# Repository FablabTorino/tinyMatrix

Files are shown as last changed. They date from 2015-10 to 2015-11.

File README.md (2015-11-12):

# TinyMatrix
A Tiny Matrix, also called e-jewel, is a little electronic Jewel that changes animations every time you press the button.

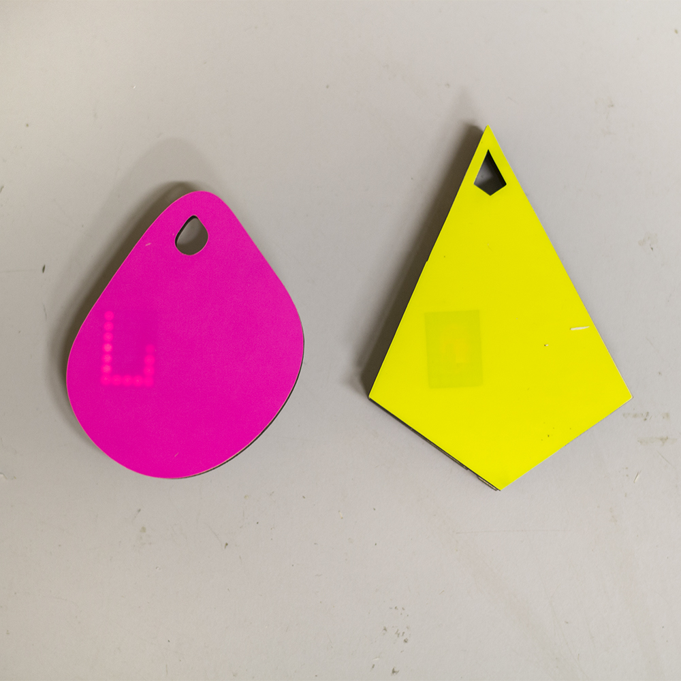
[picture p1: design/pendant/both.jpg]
 

# Programming the ATTINY4313

In order to program the AT TINY 4313 you first need to install the ATTiny core in Arduino 1.6.4.

You can do that by following [this tutorial] (https://github.com/SpenceKonde/ATTinyCore)

To connect the ATTINY to the Arduino board perhaps you can build [your own shield] (http://www.instructables.com/id/Arduino-ATtiny2313-Programming-Shield/step2/Prototype-and-Pinout/).

Now you can load Arduino's sketches. 

# Loading sketches

In this repository you will find an Arduino sketch to load some animation ([Arduino code](https://github.com/FablabTorino/tinyMatrix/tree/master/code/arduino%20programming/LedMatrix_ATtiny%20))

and a Processing sketch to create new ones ([Processing code](https://github.com/FablabTorino/tinyMatrix/tree/master/code/Processing%20sketch)). 

This last sketch will print on the console the code that you can copy and paste in Arduino.

To create new animations you have to play the processing program.

A window like this will open 

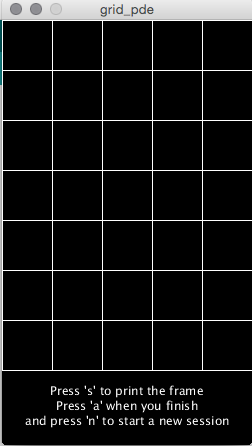
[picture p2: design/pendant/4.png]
  

Then you just draw your animation frame by frame. 

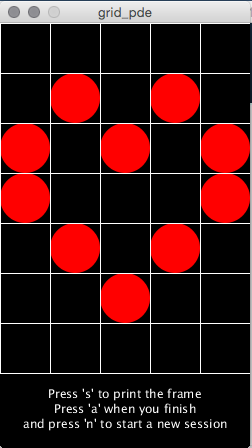
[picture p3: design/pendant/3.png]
 




To save a new frame press 's', and when you are done press 'a' so you get the number of frames and the complete code.

Now copy what Processing printed to the console

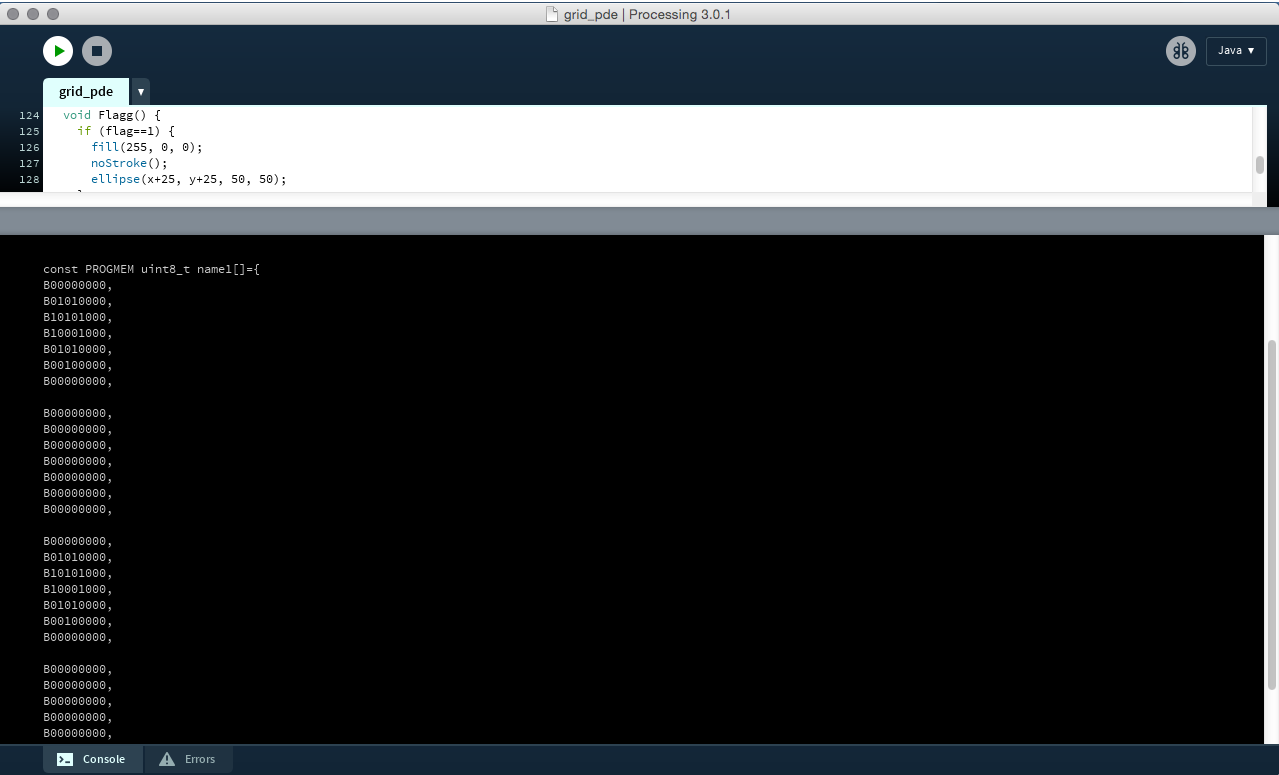
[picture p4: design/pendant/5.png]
 

and paste it in the Arduino sketch in the images.h file

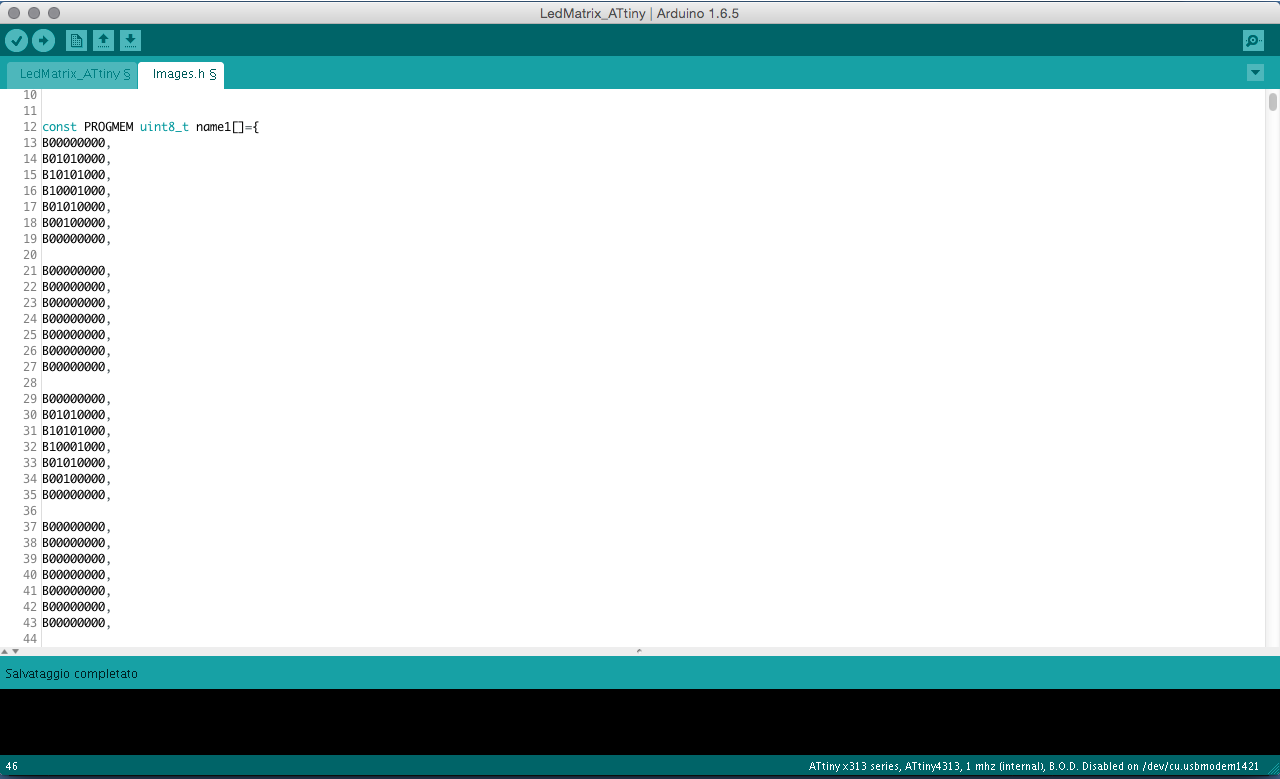
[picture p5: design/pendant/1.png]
 

now in the void loop section of the Arduino sketch create a new 'case' in the switch function

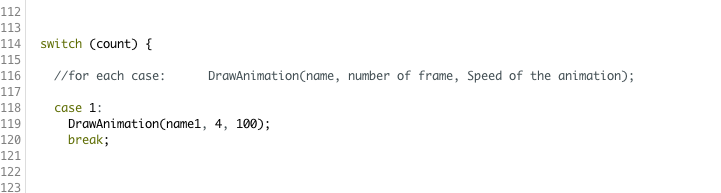
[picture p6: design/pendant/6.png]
 

now you can upload the code to the ATTINY

and you are done!

# Creating the jewel

You can download the .dxf files from [here] (https://github.com/FablabTorino/tinyMatrix/tree/master/design/DXF) or you

can draw your own, just remember to use a 6mm poplar plywood.

First thing to do is to build the structure following this instructions:
</br>
</br>
</br>
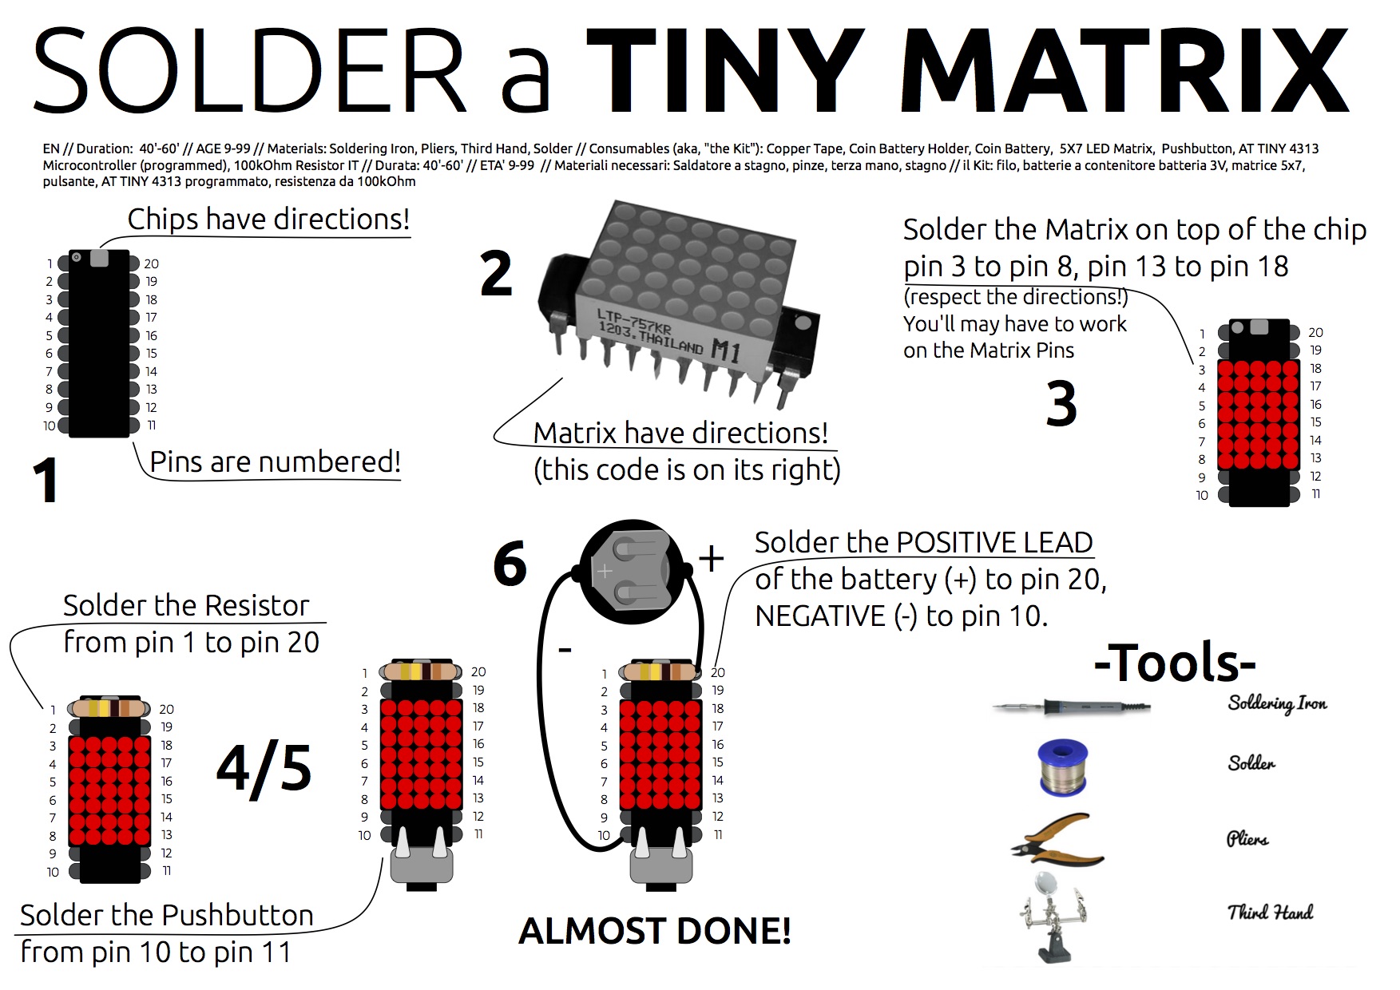
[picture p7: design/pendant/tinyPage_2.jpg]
 
</br>
</br>
</br>
The whole process should look like this:
</br>
</br>
</br>
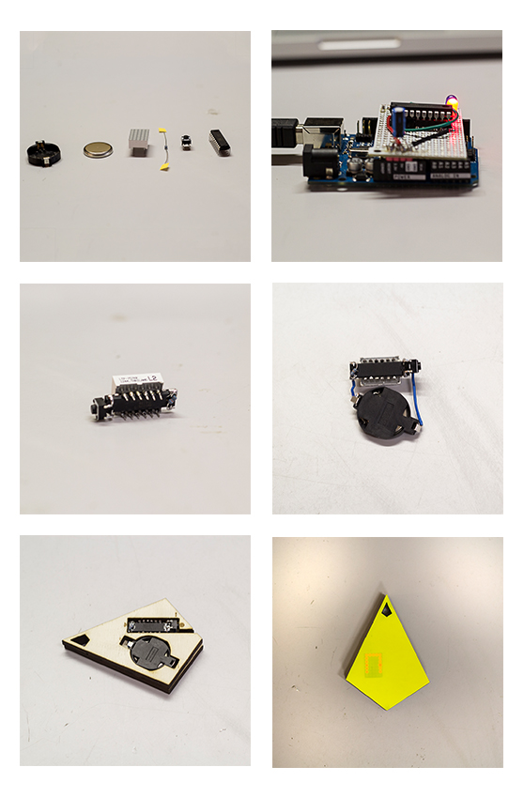
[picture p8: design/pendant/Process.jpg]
 
</br>
</br>
</br>

## Notes about the wiring
To manipulate pins and leds take a look at this scheme:
</br>
</br>
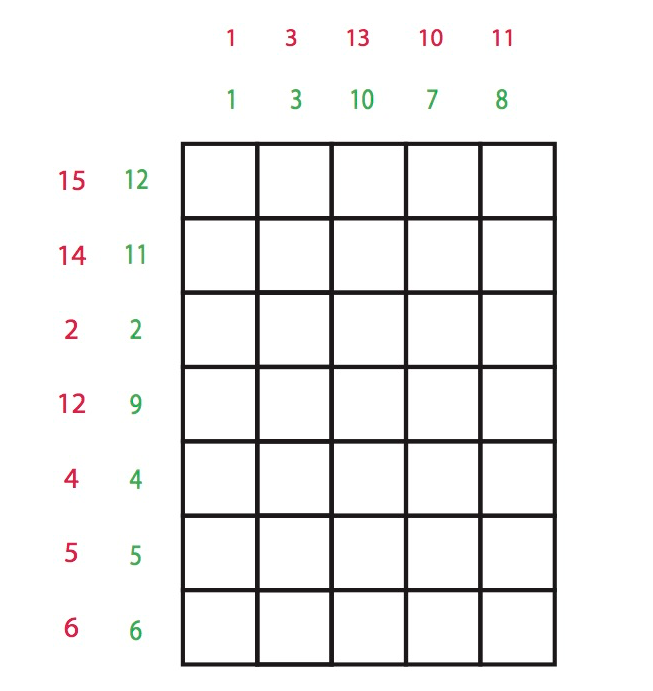
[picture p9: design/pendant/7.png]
 
</br>
</br>
Green numbers rapresent the led-matrix's pin and red numbers are the ATTINY's ones.

So, for example, if you want to turn the first led on (Up-Left) you have to set:

pin15=HIGH;
</br>
pin1=LOW;

# BOM

| part		 | Quantity | Part number | Distributor Part Number |  LINK|
| --- |:---:| :---:| :---:| :---:|
| pushbutton | 1 | 450-1650-ND | FSM4JH | 
| coin battery | 1 | P189-ND | CR2032 |
| battery  holder | 1 | BC2032-F1-ND	| BC2032-F1 |
| 100K resistors | 1 | CF18JT100KCT-ND | CF18JT100K |
| AT TINY 4313 | 1 | ATTINY4313-PU-ND | ATTINY4313-PU |
| 5X7 red matrix | 1 | 160-1555-5-ND	| LTP-757KR |

#Credits

The project was inspired By [TigerUp] (https://sites.google.com/site/tinymatrix/) and customized by Franco Magni and Federico Vanzati in 2012, at Fablab Torino, further developed by Stefano Paradiso, Tommaso Laterza and Lorenzo romagnoli in 2015.

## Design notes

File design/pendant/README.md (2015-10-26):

# Assembly instructions

you don't need any external material, casing or circuit board to assembly your pendant.
Just follow this simple guidelines.

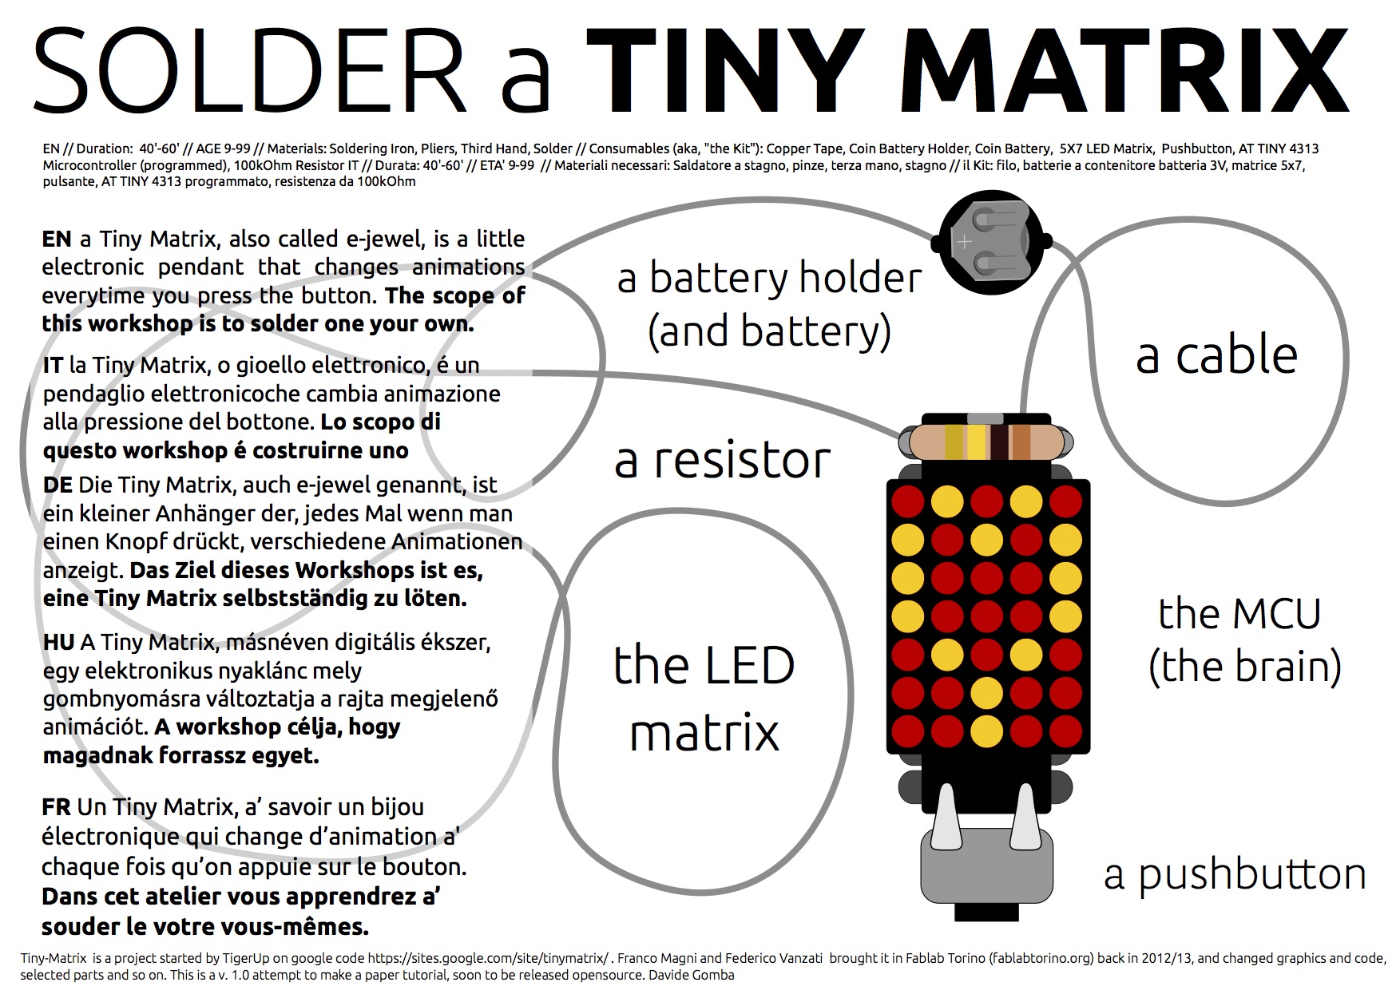
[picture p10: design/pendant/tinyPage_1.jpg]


Logo Title Text 1

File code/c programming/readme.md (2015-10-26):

##Instructions

this folder contains two version of the firmware:

**TinyMatrix**: the original project  
**TinyMatrixCountdown**: contains also a countdown (from 9 to 0) animation.

This is not an Arduino like program but there is a make file to compile it. Make sure you have the AVR-GCC toolchain installed.
To compile the program:
1. open a command shell and move to the Tiny Matrix directory
2. edit the Makefile `PROGRAMMER` field with the AVR programmer name you have
3. run the command "make all" and the HEX file to load on the ATtiny will be generated
4. run make fuse and the fuses for the Attiny4313 will be burned
5. run make program to flash the firmware on the Attiny4313

##Functioning 
TODO: description of the logic

##Credits
The origial projects was created by TigerUp (https://sites.google.com/site/tinymatrix/)

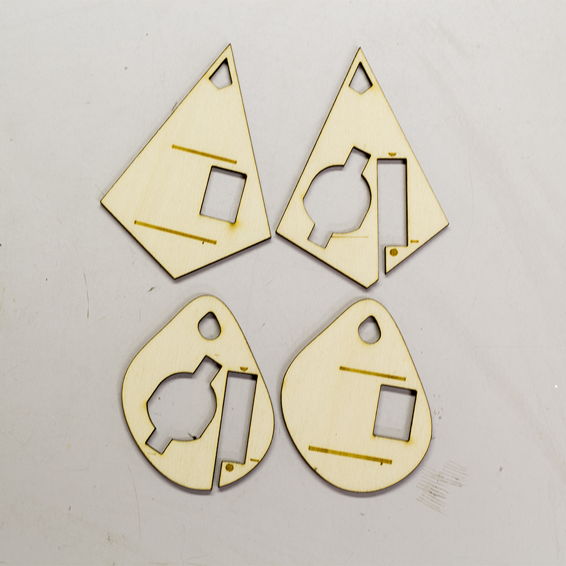
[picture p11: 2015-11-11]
design/pendant/wood.jpg

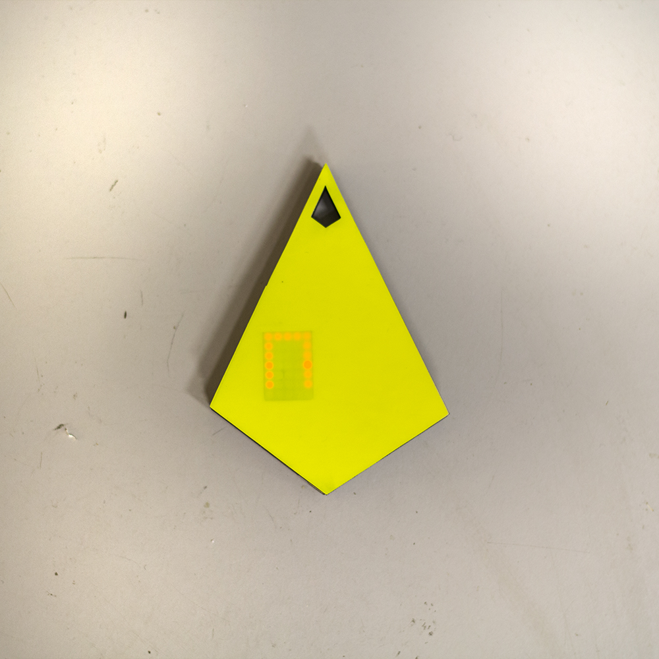
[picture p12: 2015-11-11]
design/pendant/FrontVynil.jpg

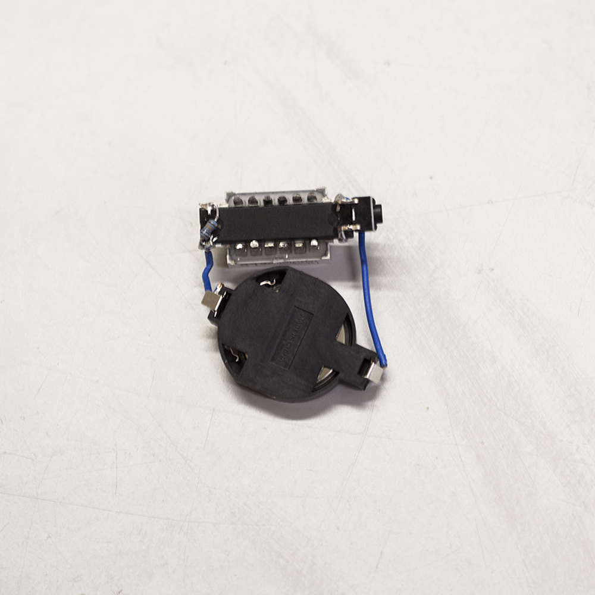
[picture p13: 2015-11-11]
design/pendant/battery.jpg

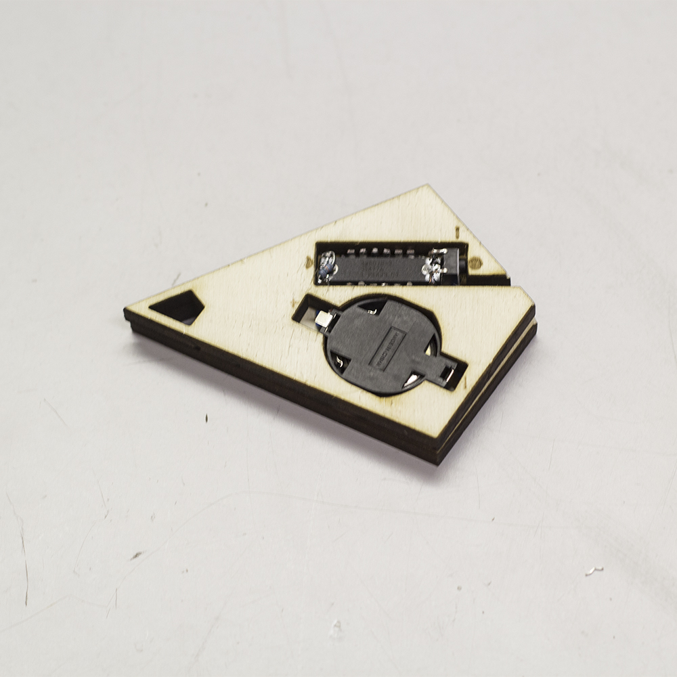
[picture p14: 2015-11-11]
design/pendant/Pendente.jpg

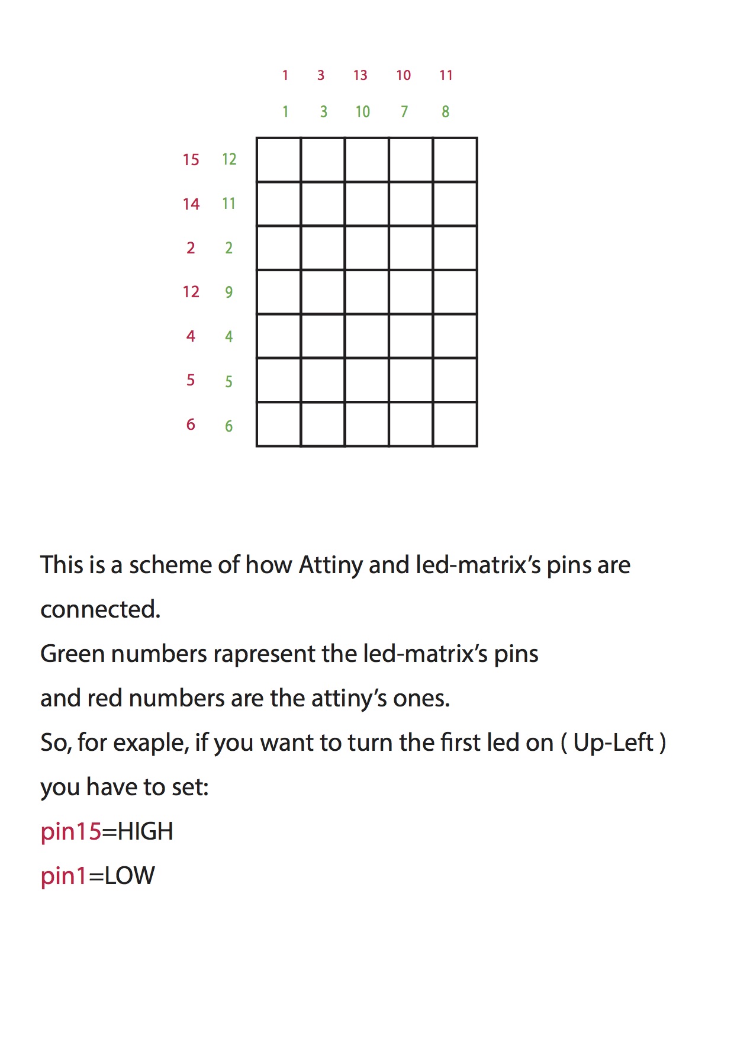
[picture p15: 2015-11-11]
design/pendant/PinsGrid.jpg

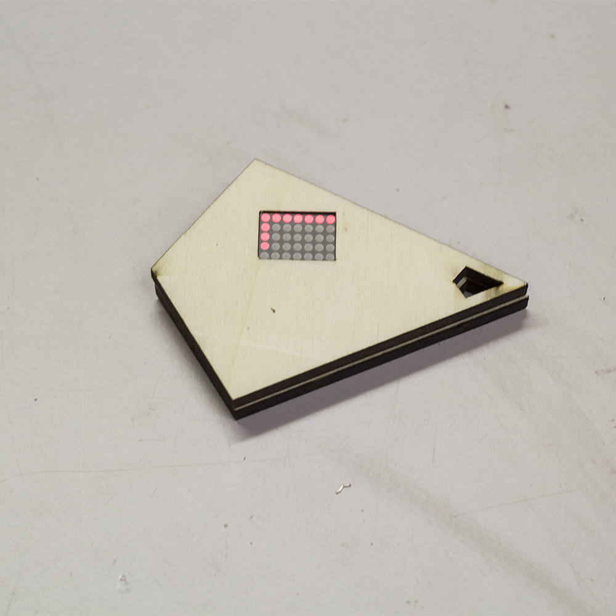
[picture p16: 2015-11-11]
design/pendant/front.jpg

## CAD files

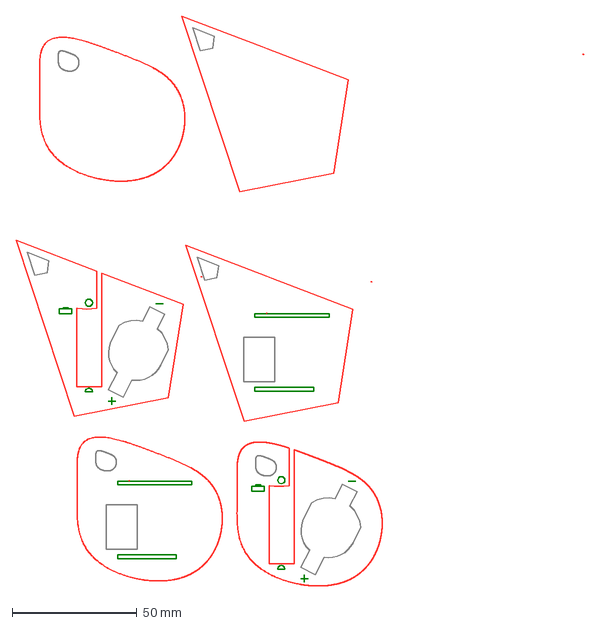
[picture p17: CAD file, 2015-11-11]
design/DXF/plotter.dxf
227.3 x 228.1 mm

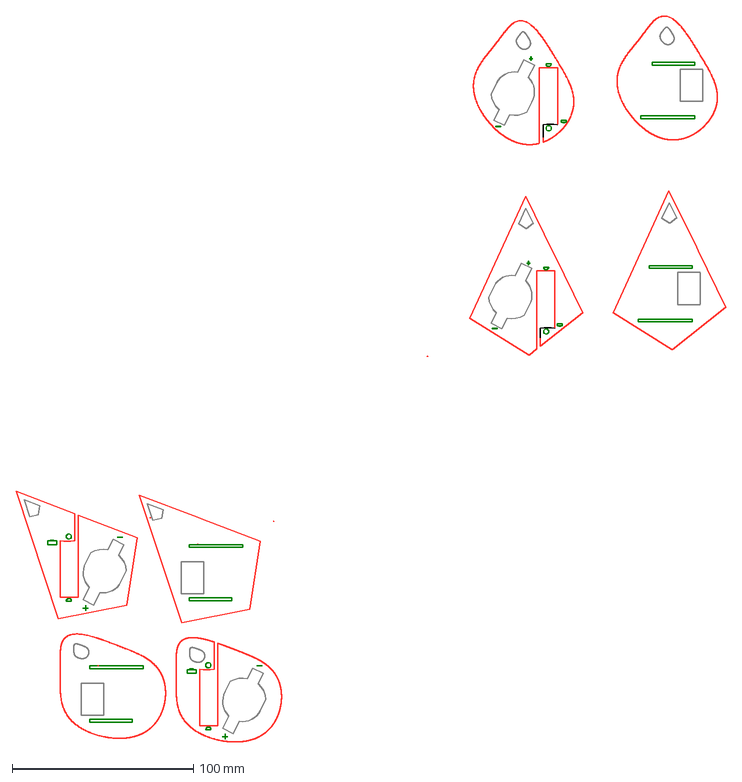
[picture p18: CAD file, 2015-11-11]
design/DXF/Lasercut.dxf
391.8 x 400.7 mm

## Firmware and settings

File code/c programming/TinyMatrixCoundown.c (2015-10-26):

////////////////////////////////////////////////////////////
// TinyMatrix.c                                           //
// copyright 2012 Tim Toner (tigeruppp/at/gmail.com)      //
// licensed under the GNU GPL v2 or newer                 //
////////////////////////////////////////////////////////////

#include <inttypes.h>
#include <stdlib.h>
#include <avr/io.h>
#include <avr/interrupt.h>
#include <avr/sleep.h>
#include <util/delay.h>
#include <avr/pgmspace.h>


// 2D LED buffer
#define ROWS		5
#define COLS		7
char bitmap[ROWS][COLS];	
char need_refresh_line;
char need_render_frame;
unsigned char current_row;		// current lit row


// globals
int mode;				// current display mode
int t, frame, frame_delay;		// animation timing variables
int b1, last_b1, b2, last_b2;		// button states


// LED refresh interrupt, called 390 times per second
ISR(TIMER0_COMPA_vect)
{
	need_refresh_line = 1;	// flag to display new row of LEDs

	if (++current_row >= ROWS) 
		current_row = 0;

	if ( (t++%frame_delay) == 0 )
		need_render_frame = 1;

}

// attach a piezo to PORTD6 and GND.
void beep()
{
	int i;

	return;
	//	This routine is disabled.
	//	I'm using PORTD6 as a redundant switch input right now.
	//	It's at the bottom corner of the chip opposite GND.
	//	Perfect place to dead-bug a pushbutton.

	for(i=0; i<100; i++)
	{
		PORTD = _BV(0) | _BV(5) | _BV(6);	_delay_us(100);
		PORTD = 0;				_delay_us(100);
	}
	
}


/////////////////////////////////////////////////////////////////////
// ATTENTION:                                                      //
// The following 3 functions serve as the LED "driver":            //
// reset_led(), set_row(r), and set_column(c).			   //
// Adjust these functions to match your LED module.                //
/////////////////////////////////////////////////////////////////////


// Two drivers are provided here.
// For Lite-on LTP-747 & LTP-757 families.

//#define LTP	747
#define LTP	757



#if LTP == 747

// Set port pins high and low in such order as to turn off the LED.
// This depends on the LED's cathode / anode arrangement etc.  
// At the same time, preserve pull-up resistors for switches.
void reset_led()
{
	// keep pull-up resistors active	
	PORTD = _BV(0) | _BV(5) | _BV(6);
		
	// hi/low the port pins to power off LED. (see datasheets)
	PORTA = _BV(1);
	PORTB = _BV(3) | _BV(5) | _BV(6);
	PORTD |= _BV(2) | _BV(3) | _BV(4);
}

// energize row r (call once)
void set_row(int r) 
{ 
	switch(r)
	{
		case 0:	PORTD |= _BV(1);	break;
		case 1:	PORTA |= _BV(0);	break;
		case 2:	PORTB |= _BV(4);	break;
		case 3:	PORTB |= _BV(1);	break;
		case 4:	PORTB |= _BV(2);	break;
	}
}

// energize col c (call once for each lit pixel in column)
void set_column(int c)
{
	switch(c)
	{
		case 6: PORTB &= ~_BV(6);		break;
		case 1: PORTD &= ~_BV(3);		break;
		case 2: PORTD &= ~_BV(2);		break;
		case 4: PORTA &= ~_BV(1);		break;
		case 3: PORTB &= ~_BV(3);		break;	
		case 5: PORTB &= ~_BV(5);		break;
		case 0: PORTD &= ~_BV(4);		break;
	}	
}

#endif

#if LTP == 757

// Set port pins high and low in such order as to turn off the LED.
// This depends on the LED's cathode / anode arrangement etc.  
// At the same time, preserve pull-up resistors for switches.
void reset_led()
{
	// keep pull-up resistors active	
	PORTD = _BV(0) | _BV(5) | _BV(6);
		
	// hi/low the port pins to power off LED. (see datasheets)
	PORTA = _BV(0);
	PORTB = _BV(1) | _BV(2) | _BV(4);
	PORTD |= _BV(1);
}

// energize row r (call once)
void set_row(int r) 
{ 
	switch(r)
	{
		case 0:	PORTD &= ~_BV(1);	break;
		case 1:	PORTA &= ~_BV(0);	break;
		case 2:	PORTB &= ~_BV(4);	break;
		case 3:	PORTB &= ~_BV(1);	break;
		case 4:	PORTB &= ~_BV(2);	break;
	}
}

// energize col c (call once for each lit pixel in column)
void set_column(int c)
{
	switch(c)
	{
		case 6: PORTB |= _BV(6);		break;
		case 1: PORTD |= _BV(3);		break;
		case 2: PORTD |= _BV(2);		break;
		case 4: PORTA |= _BV(1);		break;
		case 3: PORTB |= _BV(3);		break;	
		case 5: PORTB |= _BV(5);		break;
		case 0: PORTD |= _BV(4);		break;
	}	
}

#endif

/////////////////////////////////////////////////////////////////////
// end of LED specific hardware code                               //
/////////////////////////////////////////////////////////////////////



// render and energize the current row, based on bitmap array
void refresh_line()
{
	int c;

	reset_led();
	set_row(current_row);
	
	for (c=0; c<COLS; c++) 
		if (bitmap[current_row][c]) set_column(c);

	/* GARY - Tuesday Sept 26 11:44pm */

	need_refresh_line = 0;
}


// zero out the bitmap array
void clear_bitmap()
{
	int c,r;

	for (c=0; c<COLS; c++)
		for (r=0; r<ROWS; r++)
			bitmap[r][c] = 0;
}



/////////////////////////////////////////////////////////////////////
//                                   static 5x7 graphics / symbols //
/////////////////////////////////////////////////////////////////////
#define CHARS 24
unsigned char charset[CHARS][5] PROGMEM = 
{
	{ 0xFF, 0x41, 0x5D, 0x41, 0xFF },	// psycho 2
	{ 0x00, 0x3E, 0x22, 0x3E, 0x00 },	// psycho 1
	{ 0x0E, 0x3B, 0x17, 0x3B, 0x0E },	// skull
 	{ 0x0C, 0x12, 0x24, 0x12, 0x0C },	// heart
 	{ 0x0A, 0x00, 0x55, 0x00, 0x0A },	// flower
	{ 0x08, 0x14, 0x2A, 0x14, 0x08 },	// diamond
	{ 0x07, 0x49, 0x71, 0x49, 0x07 },	// cup
 	{ 0x22, 0x14, 0x6B, 0x14, 0x22 },	// star2
	{ 0x36, 0x36, 0x08, 0x36, 0x36 },	// star3
	{ 0x06, 0x15, 0x69, 0x15, 0x06 },	// nuke
 	{ 0x0F, 0x1A, 0x3E, 0x1A, 0x0F },	// fox
	{ 0x6C, 0x1A, 0x6F, 0x1A, 0x6C },	// alien
	{ 0x7D, 0x5A, 0x1E, 0x5A, 0x7D },	// alien
	{ 0x4E, 0x7B, 0x0F, 0x7B, 0x4E },	// alien
	{ 0x3D, 0x66, 0x7C, 0x66, 0x3D },	// alien
  	{ 0x00, 0x40, 0x7f, 0x42, 0x00 },	// 1 0x31 49
        { 0x46, 0x49, 0x51, 0x61, 0x42 },	// 2 0x32 50
        { 0x21, 0x4b, 0x45, 0x41, 0x31 },	// 3 0x33 51
        { 0x7f, 0x12, 0x14, 0x18, 0x10 },	// 4 0x34 52
        { 0x39, 0x45, 0x45, 0x45, 0x27 },	// 5 0x35 53
        { 0x30, 0x49, 0x49, 0x4a, 0x3c },	// 6 0x36 54
        { 0x03, 0x05, 0x09, 0x71, 0x01 },	// 7 0x37 55
        { 0x36, 0x49, 0x49, 0x49, 0x36 },	// 8 0x38 56
        { 0x1e, 0x29, 0x49, 0x49, 0x06 },	// 9 0x39 57
//	{ 0x, 0x, 0x, 0x, 0x }
};


// renders character c onto the bitmap
void render_character(int c)
{
	int x,y, byte;

	clear_bitmap();

	for (y=0; y<ROWS; y++)
	{
		byte = pgm_read_byte(&(charset[c][y]));

		for (x=0; x<COLS; x++)
		{
			if (byte & _BV(0)) bitmap[y][x] = 1;
			byte = byte >> 1;
		}		
	}	
}


/////////////////////////////////////////////////////////////////////
//                                                      animations //
/////////////////////////////////////////////////////////////////////

void render_countdown()
{
	frame_delay = 250;


	switch (frame%20)
	{
		case 0:  render_character(23);	break;	
		case 1:  clear_bitmap();	break;	
		case 2:  render_character(22);	break;	
		case 3:  clear_bitmap();	break;	
		case 4:  render_character(21);	break;	
		case 5:  clear_bitmap();	break;	
		case 6:  render_character(20);	break;	
		case 7:  clear_bitmap();	break;	
		case 8:  render_character(19);	break;	
		case 9:  clear_bitmap();	break;	
		case 10: render_character(18);	break;	
		case 11: clear_bitmap();	break;	
		case 12: render_character(17);	break;	
		case 13: clear_bitmap();	break;	
		case 14: render_character(16);	break;	
		case 15: clear_bitmap();	break;	
		case 16: render_character(15);	break;	
		case 17: clear_bitmap();	break;	
	}
}

void render_checkerboard()
{
	int c,r;

	frame_delay = 300;

	// fill the frame buffer with a procedural pattern

	for (c=0; c<COLS; c++)
		for (r=0; r<ROWS; r++)
		{
			bitmap[r][c] = (r + c + frame) % 2 ;
		}
}

void render_rain()
{
	int y;

	frame_delay = 20;
	clear_bitmap();

	// this is a modulus based particle system

	y = frame%19;	
	if (y<COLS) bitmap[0][y] = 1;

	y = frame%11;	
	if (y<COLS) bitmap[2][y] = 1;

	y = frame%17;	
	if (y<COLS) bitmap[4][y] = 1;
}


void render_psycho()
{
	frame_delay = 30;

	// simple 2 frame animation
	
	if (frame%2) render_character(0);
	else render_character(1);
}

void render_heartbeat()
{
	frame_delay = 40;

	// how to sequence frames using case statement

	switch (frame%10)
	{
		case 0: render_character(3);	break;	
		case 1: clear_bitmap();	break;	
		case 2: render_character(3);	break;	
		case 3: clear_bitmap();	break;	
	}
}

void render_fire()
{
	int r;

	frame_delay = 40;
	clear_bitmap();

	// another modulus based particle system

	// fire body
	r = (frame+0)%3;	bitmap[0][6-r] = 1;
	r = (frame+1)%2;	bitmap[1][6-r] = 1;
	r = (frame+0)%2;	bitmap[2][6-r] = 1;
	r = (frame+1)%2;	bitmap[3][6-r] = 1;
	r = (frame+1)%3;	bitmap[4][6-r] = 1;

	r = (frame+1)%5;	bitmap[1][6-r] = 1;
	r = (frame+0)%3;	bitmap[2][6-r] = 1;
	r = (frame+2)%5;	bitmap[3][6-r] = 1;

	r = (frame+4)%4;	bitmap[0][6-r] = 1;
	r = (frame+1)%4;	bitmap[1][6-r] = 1;
	r = (frame+0)%4;	bitmap[2][6-r] = 1;
	r = (frame+3)%4;	bitmap[3][6-r] = 1;
	r = (frame+2)%4;	bitmap[4][6-r] = 1;

	// sparks
	r = (frame+0)%19;	if (r<COLS) bitmap[0][6-r] = 1;
	r = (frame+0)%6;	if (r<COLS) bitmap[1][6-r] = 1;
	r = (frame+0)%7;	if (r<COLS) bitmap[2][6-r] = 1;
	r = (frame+2)%6;	if (r<COLS) bitmap[3][6-r] = 1;
	r = (frame+0)%17;	if (r<COLS) bitmap[4][6-r] = 1;

}




// renders the correct image / animation onto the bitmap
#define MODES 28
void render_buffer()
{
	frame++;
	need_render_frame = 0;
	
	switch(mode)
	{
		case 1:render_checkerboard();	break;
		case 2:render_psycho();	break;
		case 3:render_heartbeat();	break;
		case 4:render_rain();		break;
		case 5:render_fire();		break;
		case 6:render_character(2);	break;
		case 7: render_character(3);	break;
		case 8: render_character(4);	break;
		case 9: render_character(5);	break;
		case 10: render_character(6);	break;
		case 11: render_character(7);	break;
		case 12: render_character(8);	break;
		case 13: render_character(9);	break;
		case 14: render_character(10);	break;
		case 15: render_character(11);	break;
		case 16: render_character(12);	break;
		case 17: render_character(13);	break;
		case 18: render_character(14);	break;
		case 19: render_character(15);	break;
		case 20: render_character(16);	break;
		case 21: render_character(17);	break;
		case 22: render_character(18);	break;
		case 23: render_character(19);	break;
		case 24: render_character(20);	break;
		case 25: render_character(21);	break;
		case 26: render_character(22);	break;
		case 27: render_character(23);	break;
                case 28: render_countdown();	break;
	}
}

// poll the pushbuttons, and record their states.
// increment/decrement 'mode' in response.
void check_inputs()
{
	// button 1 state (PORTD0 or PORTD6)
	if ((PIND & _BV(0)) == 0 || (PIND & _BV(6)) == 0) b1++;	else b1 = 0;

	// button 2 state (PORTD5)
	if ((PIND & _BV(5)) == 0) b2++;	else b2 = 0;

	// rudimentary de-bouncing
	if (b2 == 10) 		{ beep(); mode--; need_render_frame = 1; }
	if (b1 == 10) 		{ beep(); mode++; need_render_frame = 1; }

	// wraparound (optional)
	if (mode > MODES) mode = 1;
	if (mode < 1) mode = MODES;
}



////////////////////////////////////////////////////////////
//                                         initialization //
////////////////////////////////////////////////////////////
void init()
{
	// set output pins
	DDRA = _BV(0) | _BV(1);
	DDRB = _BV(1) | _BV(2) | _BV(3) | _BV(4) | _BV(5) | _BV(6);
	DDRD = _BV(1) | _BV(2) | _BV(3) | _BV(4);

	// setup Timer/Counter0 for LED refresh
	TCCR0A = _BV(WGM01);	// Set CTC mode
	TCCR0B = _BV(CS02);	// Set prescaler clk/256
	OCR0A = 40;		// ~ 390 interrupts/sec (by 5 cols = ~78fps)
	TIMSK = _BV(OCIE0A);	// Enable T/C 0A

	sei();

	mode = 6;		// Initial display pattern
}

//////////////////////////////////////////////////////////// 
//                                              main loop // 
//////////////////////////////////////////////////////////// 
void main_loop() 
{ 
	for (;;)
	{
		if (need_render_frame) render_buffer();		
		if (need_refresh_line)	
		{	
			refresh_line();
			check_inputs();
		}
	}	
}




////////////////////////////////////////////////////////////
//                                                  main  //
////////////////////////////////////////////////////////////
int main (void)
{
	init();
	main_loop();
	return (0);
}

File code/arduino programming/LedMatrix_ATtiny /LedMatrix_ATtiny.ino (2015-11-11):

#include <avr/pgmspace.h>
int idx = 0; unsigned long last;
#include "Images.h"
int Col[] = {1, 3, 13, 10, 11};
int Rig[] = {15, 14, 2, 12, 4, 5, 6};
int x, y;
unsigned long lastMillis = 0;
int Frame = -1;
int count = 0;
const int buttonPin = 8;     // the number of the pushbutton pin
int lastDebounceTime = 0;
int debounceDelay = 50;
int buttonState;             // the current reading from the input pin
int lastButtonState = HIGH;




void setup() {

  pinMode(buttonPin, INPUT_PULLUP);

  for (int i = 0; i < 5; i++) {
    pinMode( Col[i], OUTPUT ); //pin 1 lmatrix
    digitalWrite(Col[i], HIGH);
  }
  for (int i = 0; i < 7; i++) {
    pinMode( Rig[i], OUTPUT ); //pin 1 lmatrix
    digitalWrite(Rig[i], LOW);
  }
}


void pixel( int x, int y) {
  digitalWrite(Rig[x], HIGH);
  digitalWrite(Col[y], LOW);
  delayMicroseconds(5);
  digitalWrite(Rig[x], LOW);
  digitalWrite(Col[y], HIGH);
  delayMicroseconds(5);

}

void DrawFrameCompact(const uint8_t* frame2) {
  for (int a = 0; a < 7; a++) {
    for (int b = 0; b < 5; b++) {
      if ( bitRead(pgm_read_byte(&frame2[a]), 7 - b) ) {
        pixel(a, b);
      }
    }
  }
}


void DrawAnimation(const uint8_t* frame2, int d, int velocit) {



  if (millis() - lastMillis > velocit) {
    if ( Frame < d-1 ) {
      Frame = Frame + 1;
    }
    else {
      Frame = 0;
    }
    lastMillis = millis();
  }
  for (int a = Frame * 7; a < (7 * Frame) + 7; a++) {
    for (int b = 0; b < 5; b++) {
      if ( bitRead(pgm_read_byte(&frame2[a]), 7 - b) ) { //pgm_read_byte(&frame2[a]) is used to read variables allocated in flash memory
        pixel(a - (Frame * 7), b);
      }
    }
  }
}



void loop() {

  int reading = digitalRead(buttonPin);
  if (reading != lastButtonState) {
    lastDebounceTime = millis();
  }
  if ((millis() - lastDebounceTime) > debounceDelay) {
    if (reading != buttonState) {
      buttonState = reading;


      if (buttonState == LOW) {
        Frame=0;
        count++;
      }
    }
  }
  lastButtonState = reading;



  switch (count) {
    
    case 1:
      DrawAnimation(vertigo, 35, 50);
      break;

    case 2:
      DrawAnimation(barretta, 4, 50);
      break;

    case 3:
      DrawAnimation(pattern1, 2, 100);
      break;

     case 4:
      DrawAnimation(pattern2, 4, 100);
      break;

    case 5:
      DrawAnimation(heart, 6, 140);
      break;

    case 6:
      DrawAnimation(rain, 16, 100);
      break;

    case 7:
      DrawAnimation(operae, 7, 400);
      break;

    case 8:
      DrawAnimation(pinball, 30, 100);
      break;

    case 9:
      DrawAnimation(snake, 69, 60);
      break;


      
     case 10:
     count=1;
    break;

    
  }



}

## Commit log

2015-10-26 added BOM
2015-11-04 Ported TinyMatrix to arduino
